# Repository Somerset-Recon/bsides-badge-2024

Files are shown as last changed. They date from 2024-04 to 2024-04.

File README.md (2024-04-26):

# BSides Badge 2024
<div align="center">
<table>
  <tr>
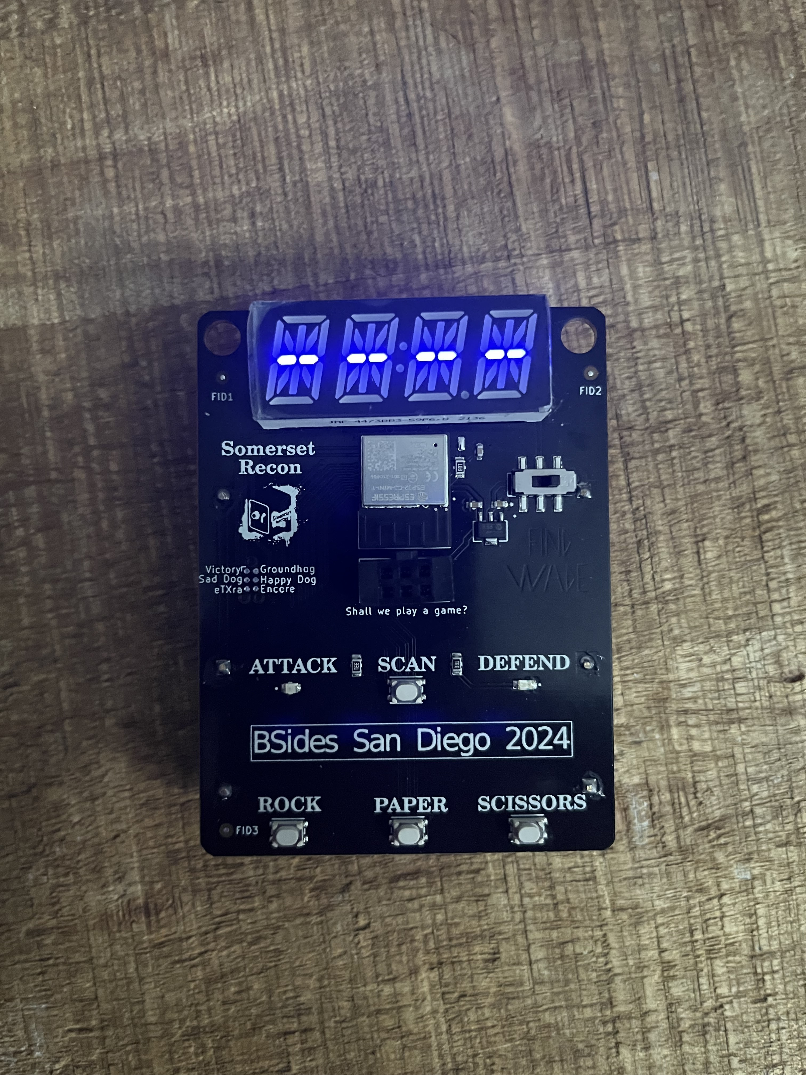
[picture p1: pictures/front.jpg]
    <td></td>
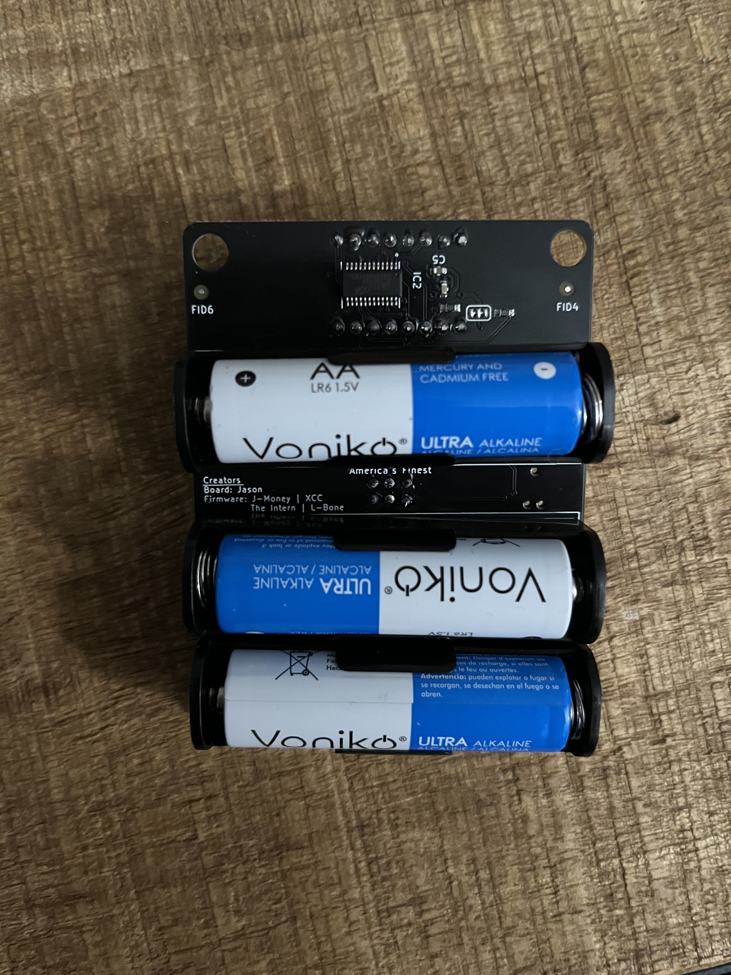
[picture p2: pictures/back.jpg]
    <td></td>
  </tr>
  <tr>
    <td><em><center>Front</center></em></td>
    <td><em><center>Back</center></em></td>
  </tr>
  <tr>
 </table>
<table>
  <tr>
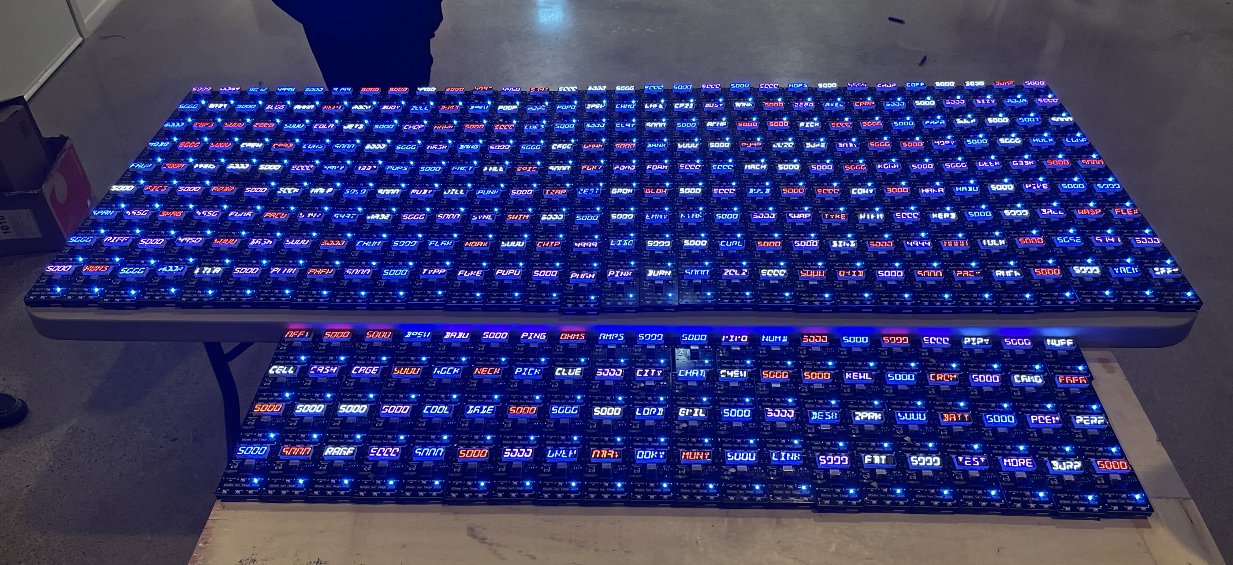
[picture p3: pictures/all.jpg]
    <td></td>
  </tr>
  <tr>
    <td align=center><em>Flashed Badges</em></td>
  </tr>
  <tr>
 </table>
 </div>

This repository contains hardware and firmware information needed to create and/or modify the Bsides Conference 2024 badge. All Gerber files, kiCad schematics, and other hardware-related files can be found in the "kiCad" folder. Associated source code and required libraries can be found in the "software" folder. We welcome BSides CTF players to submit writeups. Badge related writeups will be populated below.

Disclaimer: Somerset Recon is not liable nor responsible for any and all forks, branches, and duplication of the badge hardware or software created by an entity other than Somerset Recon.

The Badge for the San Diego Bsides Conference is a game that involves wireless rock-paper-scissors. There are hidden hacking challenges accessible over UART with a Wargames movie theme. 400 badges were distributed at the BSides San Diego 2024 Conference.

## Gameplay

The object of the game was to score the most points. Points were earned by hacking other players. The badges have two states: Attack mode and defend mode. 

 	A red LED on a badge will indicate that the player is in attack mode. Players will click the scan button. During a scan, BLE on the baddge will search for devices that are advertising (devices in defend mode). Once a connection is established, the player will be notified to choose rock, paper or scissors. The attacker gains points for each second they are connected to a defender. Once the defender notices that they are being attacked, they will choose rock, paper, or scissors. 
## WOPR Interface
<div align="center">
<table>
  <tr>
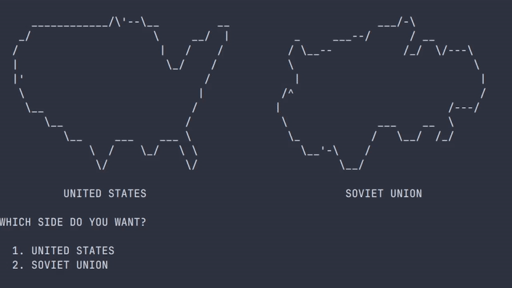
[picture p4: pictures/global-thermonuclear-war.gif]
    <td></td>
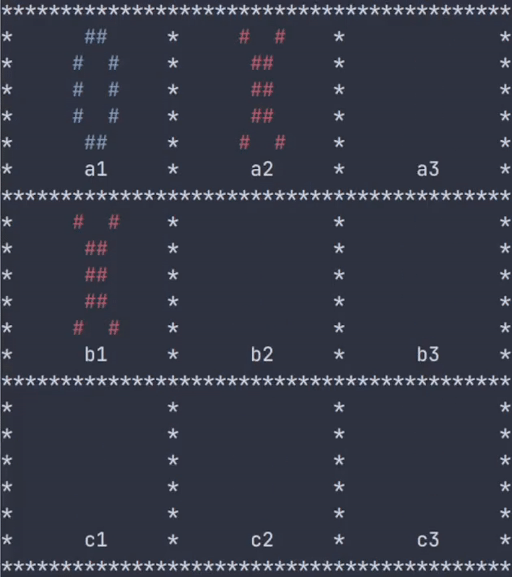
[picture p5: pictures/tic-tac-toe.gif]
    <td></td>
  </tr>
  <tr>
    <td align=center><em>Global Thermonuclear War</em></td>
    <td align=center><em>Tic-Tac-Toe</em></td>
  </tr>
  <tr>
</table>
</div>
Various challenges in the form of WOPR games are accessible using UART over the SAO connector. Each challenge contains its own flag to earn points in the BSides CTF.

# Flashing Instructions
> [!NOTE]
> In the latest source code, a cool glitch-like display will appear for the custom name when "SCAN" is held at boot. The conference badges were flashed with earlier firmware and do not have this feature. To add this glitch-like display, the badge must be flashed with the latest source code.
## Materials
- Arduino IDE
- TAG Connector (6-pin without legs)
## Procedure
1. Copy the Ticker library in this repository to the arduino library folder. Do *not* download the Ticker library via the Library Manager.
2. Open the Arduino IDE.
3. Open the source code file "latest.ino". All files in the folder should be automatically added when loaded.
4. Navigate to Board Manager and download the "esp32" board by Espressif Systems.
5. Turn on the badge and connect the TAG Connector to the TAG port. Plug the TAG connect to your computer via USB.
6. Select the board "ESP32C3 Dev Module" and choose the port that the badge is connected to.
7. Press Upload. If the compilation fails, ensure you have all necessary libraries downloaded.

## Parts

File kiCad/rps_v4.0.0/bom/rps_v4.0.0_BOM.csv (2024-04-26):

Id | Designator | Footprint | Quantity | Designation | Supplier and ref
1 | BT1,BT2,BT3 | BatteryHolder_Keystone_2460_1xAANO_HOLES | 3 | 2460
2 | R2,R1 | R-0805 | 2 | 330
3 | D2 | LED_0805_Red | 1 | RED
4 | U2 | SILSMART_DISPLAY | 1 | SILSMART_DISPLAY
5 | SW5 | ON_OFF_SW_JS202011SCQN | 1 | JS202011SCQN
6 | SW1,SW2,SW3,SW4 | PTS815_button | 4 | PTS815 SJM 250 SMTR LFS
7 | FID3,FID2,FID1,FID5,FID6,FID4 | Fiducial_0.75mm_Mask2.25mm | 6 | Fiducial
8 | C2,C3,C1 | CAP_0603_1UF | 3 | 1UF
9 | R3 | RES_0805_10K | 1 | 10K
10 | D1 | LED_0805_BLUE | 1 | BLUE
11 | J1 | SAO_CONN6_D03-ST-BK_SUL | 1 | SAO
12 | U1 | ESP32-C3-MINI-1-N4 | 1 | ESP32-C3-MINI-1-N4
13 | U3 | MCP1700_LDO | 1 | MCP1700T-3302E/MB
14 | TP1 | SolderWirePad_1x01_SMD_1x2mm | 1 | TestPoint
15 | IC1 | HT16K33A-24SOP | 1 | HT16K33
16 | R5,R4 | 0603 | 2 | 2K2
17 | C5 | CAP_0603_10UF | 1 | 10UF
18 | C4 | CAP_0603_0.1UF | 1 | 0.1UF

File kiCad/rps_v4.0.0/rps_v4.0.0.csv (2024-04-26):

Source: | /home/chargen/badge_2024/kiCad/rps_v4.0.0/rps_v4.0.0.kicad_sch
Date: | Sun 14 Jan 2024 09:23:05 AM PST
Tool: | Eeschema 7.0.10-7.0.10~ubuntu22.04.1
Generator: | /usr/share/kicad/plugins/bom_csv_grouped_by_value.py
Component Count: | 32
Collated Components:
Item | Qty | Reference(s) | Value | LibPart | Footprint | Datasheet | DNP | Availability | Check_prices | Description | MANUFACTURER | MAXIMUM_PACKAGE_HEIGHT | MF | MP | PARTREV | PROD_ID | Package | Price | Purchase-URL | STANDARD | SnapEDA_Link
1 | 3 | BT1, BT2, BT3 | 2460 | rps_v4.0.0_symbols_library:2460_AA_Battery_Holder | rps_v4.0_footprint_library:BatteryHolder_Keystone_2460_1xAANO_HOLES | https://www.keyelco.com/userAssets/file/M65p28.pdf |  |  |  | Battery Holder for the AA batteries to power the board. | Keystone Electronics | 13.89mm |  |  |  |  |  | .70 | https://www.digikey.com/en/products/detail/keystone-electronics/2460/280629 |  | https://www.digikey.com/en/models/280629
2 | 3 | C1, C2, C3 | 1UF | rps_v4.0.0_symbols_library:Capacitor-0603 | rps_v4.0_footprint_library:0603
3 | 1 | C4 | 0.1UF | rps_v4.0.0_symbols_library:Capacitor-0603 | rps_v4.0_footprint_library:0603 | https://mm.digikey.com/Volume0/opasdata/d220001/medias/docus/658/CL10B104KB8NNWC_Spec.pdf |  |  |  |  |  |  |  |  |  |  |  | .006 | https://www.digikey.com/en/products/detail/samsung-electro-mechanics/CL10B104KB8NNWC/3887593 |  | https://www.digikey.com/en/models/3887593
4 | 1 | C5 | 10UF | rps_v4.0.0_symbols_library:Capacitor-0603 | rps_v4.0_footprint_library:0603 | https://mm.digikey.com/Volume0/opasdata/d220001/medias/docus/609/CL10A106MQ8NNNC_Spec.pdf |  |  |  |  |  |  |  |  |  |  |  | .030 | https://www.digikey.com/en/products/detail/samsung-electro-mechanics/CL10A106MQ8NNNC/3886777 |  | https://www.digikey.com/en/models/3886777
5 | 1 | D3 | RED | rps_v4.0.0_symbols_library:LED-0805 | rps_v4.0_footprint_library:LED-0805 | https://dammedia.osram.info/media/resource/hires/osram-dam-5178068/LS%20R976_EN.pdf |  |  |  |  |  |  |  |  |  |  |  | .063 | https://www.digikey.com/en/products/detail/ams-osram-usa-inc/LS-R976-NR-1/1227987 |  | https://www.digikey.com/en/models/1227987
6 | 1 | D4 | BLUE | :LED-0805_1 | rps_v4.0_footprint_library:LED-0805 | https://optoelectronics.liteon.com/upload/download/DS22-2000-233/LTST-C171TBKT(0630).pdf |  |  |  |  |  |  |  |  |  |  |  | .11 | https://www.digikey.com/en/products/detail/liteon/LTST-C171TBKT/388528 |  | https://www.digikey.com/en/models/388528
7 | 6 | FID1, FID2, FID3, FID4, FID5, FID6 | Fiducial | rps_v4.0.0_symbols_library:Fiducial | rps_v4.0_footprint_library:Fiducial_0.75mm_Mask2.25mm | ~
8 | 1 | IC2 | HT16K33 | rps_v4.0.0_symbols_library:HT16K33 | rps_v4.0_footprint_library:HT16K33 | https://www.digikey.com/en/htmldatasheets/production/2070902/0/0/1/ht16k33 |  |  |  |  |  |  |  |  |  | IC-14891 |  | .61
9 | 1 | J1 | SAO | rps_v4.0.0_symbols_library:CONN_02x03_SFH11-PBPC-D03-ST-BK | rps_v4.0_footprint_library:SAO_CONN6_D03-ST-BK_SUL | https://s3.amazonaws.com/catalogspreads-pdf/PAGE123%20.100%20SFH11%20SERIES%20FEMALE%20HDR%20ST%20RA.pdf |  |  |  |  |  |  |  |  |  |  |  | .42 | https://www.digikey.com/en/products/detail/sullins-connector-solutions/SFH11-NBPC-D03-ST-BK/4558818 |  | https://www.digikey.com/en/models/4558878
10 | 3 | R1, R2, R4 | 10K | rps_v4.0.0_symbols_library:R_0805 | rps_v4.0_footprint_library:R-0805 | https://www.seielect.com/catalog/sei-rmcf_rmcp.pdf |  |  |  |  |  |  |  |  |  |  |  | .005 | https://www.digikey.com/en/products/detail/stackpole-electronics-inc/RMCF0805JT10K0/1757762 |  | https://www.digikey.com/en/models/1757762
11 | 2 | R6, R7 | 2K2 | rps_v4.0.0_symbols_library:R-0603 | rps_v4.0_footprint_library:0603 | https://www.yageo.com/upload/media/product/productsearch/datasheet/rchip/PYu-RT_1-to-0.01_RoHS_L_15.pdf |  |  |  |  |  |  |  |  |  |  |  | .046 | https://www.digikey.com/en/products/detail/yageo/RT0603BRD072K2L/1072430 |  | https://www.digikey.com/en/models/1072430
12 | 1 | SW1 | PTS815 SJM 250 SMTR LFS | :PTS815_SJM_250_SMTR_LFS_1 | rps_v4.0_footprint_library:PTS815_button | https://www.ckswitches.com/media/2728/pts815.pdf |  |  |  |  | C&K |  |  |  |  |  |  | .12 | https://www.digikey.com/en/products/detail/c-k/PTS815-SJM-250-SMTR-LFS/9947846 |  | https://www.digikey.com/en/models/9947846
13 | 1 | SW2 | PTS815 SJM 250 SMTR LFS | :PTS815_SJM_250_SMTR_LFS_2 | rps_v4.0_footprint_library:PTS815_button | https://www.ckswitches.com/media/2728/pts815.pdf |  |  |  |  | C&K |  |  |  |  |  |  | .12 | https://www.digikey.com/en/products/detail/c-k/PTS815-SJM-250-SMTR-LFS/9947846 |  | https://www.digikey.com/en/models/9947846
14 | 1 | SW3 | PTS815 SJM 250 SMTR LFS | :PTS815_SJM_250_SMTR_LFS_3 | rps_v4.0_footprint_library:PTS815_button | https://www.ckswitches.com/media/2728/pts815.pdf |  |  |  |  | C&K |  |  |  |  |  |  | .12 | https://www.digikey.com/en/products/detail/c-k/PTS815-SJM-250-SMTR-LFS/9947846 |  | https://www.digikey.com/en/models/9947846
15 | 1 | SW4 | PTS815 SJM 250 SMTR LFS | rps_v4.0.0_symbols_library:PTS815_SJM_250_SMTR_LFS | rps_v4.0_footprint_library:PTS815_button | https://www.ckswitches.com/media/2728/pts815.pdf |  |  |  |  | C&K |  |  |  |  |  |  | .12 | https://www.digikey.com/en/products/detail/c-k/PTS815-SJM-250-SMTR-LFS/9947846 |  | https://www.digikey.com/en/models/9947846
16 | 1 | SW5 | JS202011SCQN | rps_v4.0.0_symbols_library:ON_OFF_6PIN_JS202011SCQN | rps_v4.0_footprint_library:ON_OFF_SW_JS202011SCQN | https://www.ckswitches.com/media/1422/js.pdf |  |  |  |  |  |  |  |  |  |  |  | .47 | https://www.digikey.com/en/products/detail/c-k/JS202011SCQN/2094299 |  | https://www.digikey.com/en/models/2094299
17 | 1 | TP1 | TestPoint | rps_v4.0.0_symbols_library:TestPoint | rps_v4.0_footprint_library:SolderWirePad_1x01_SMD_1x2mm | ~
18 | 1 | U1 | ESP32-C3-MINI-1-N4 | rps_v4.0.0_symbols_library:ESP32-C3-MINI-1-N4 | rps_v4.0_footprint_library:ESP32-C3-MINI-1-N4 | https://www.espressif.com/sites/default/files/documentation/esp32-c3-mini-1_datasheet_en.pdf |  | In Stock | https://www.snapeda.com/parts/ESP32-C3-MINI-1-N4/Espressif+Systems/view-part/?ref=eda | Bluetooth, WiFi 802.11b/g/n, Bluetooth v5.0 Transceiver Module 2.412GHz ~ 2.484GHz PCB Trace Surface Mount | Espressif Systems | 2.55mm | Espressif Systems | ESP32-C3-MINI-1-N4 | v1.0 |  | SMD-53 Espressif Systems | 1.80 | https://www.snapeda.com/api/url_track_click_mouser/?unipart_id=5656579&manufacturer=Espressif Systems&part_name=ESP32-C3-MINI-1-N4&search_term=esp32-c3-mini | Manufacturer Recommendations | https://www.snapeda.com/parts/ESP32-C3-MINI-1-N4/Espressif+Systems/view-part/?ref=snap
19 | 1 | U2 | SILSMART_DISPLAY | rps_v4.0.0_symbols_library:SILSMART_DISPLAY | rps_v4.0_footprint_library:SILSMART_DISPLAY | https://cdn.sparkfun.com/assets/a/9/d/a/4/JMF-4473BS4-059-P6.8.pdf |  |  |  |  |  |  |  |  |  | COMP-14892 |  | 2.50 | https://www.digikey.com/en/products/detail/sparkfun-electronics/COM-21217/16892550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
20 | 1 | U3 | MCP1700T-3302E/MB | rps_v4.0.0_symbols_library:MCP1700T-3302E_MB | rps_v4.0_footprint_library:MCP1700_LDO | MCP1700T-3302E/MBhttps://ww1.microchip.com/downloads/en/DeviceDoc/MCP1700-Data-Sheet-20001826F.pdf

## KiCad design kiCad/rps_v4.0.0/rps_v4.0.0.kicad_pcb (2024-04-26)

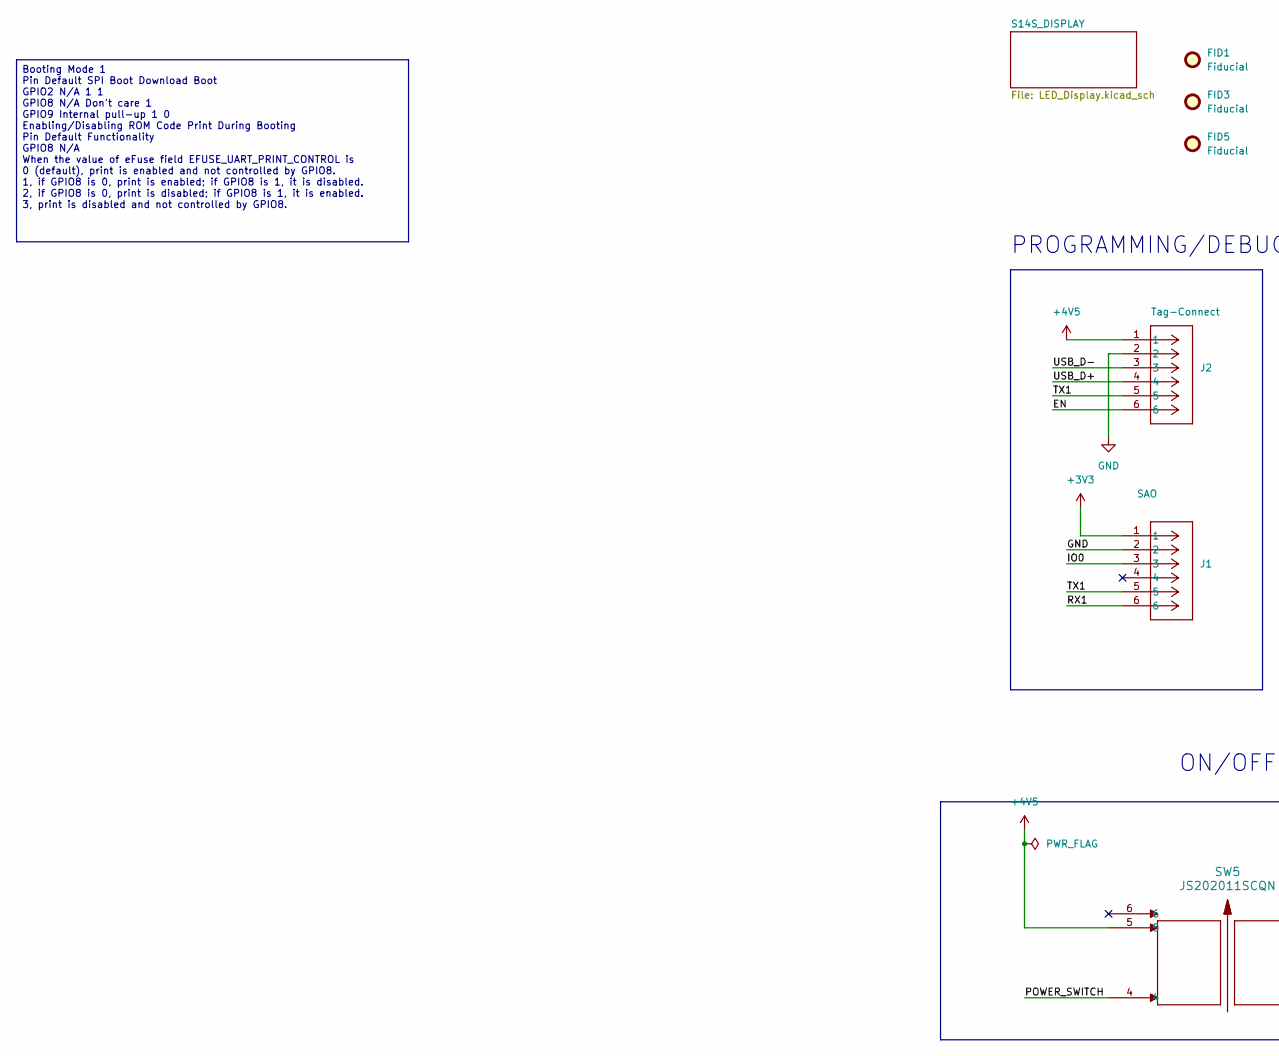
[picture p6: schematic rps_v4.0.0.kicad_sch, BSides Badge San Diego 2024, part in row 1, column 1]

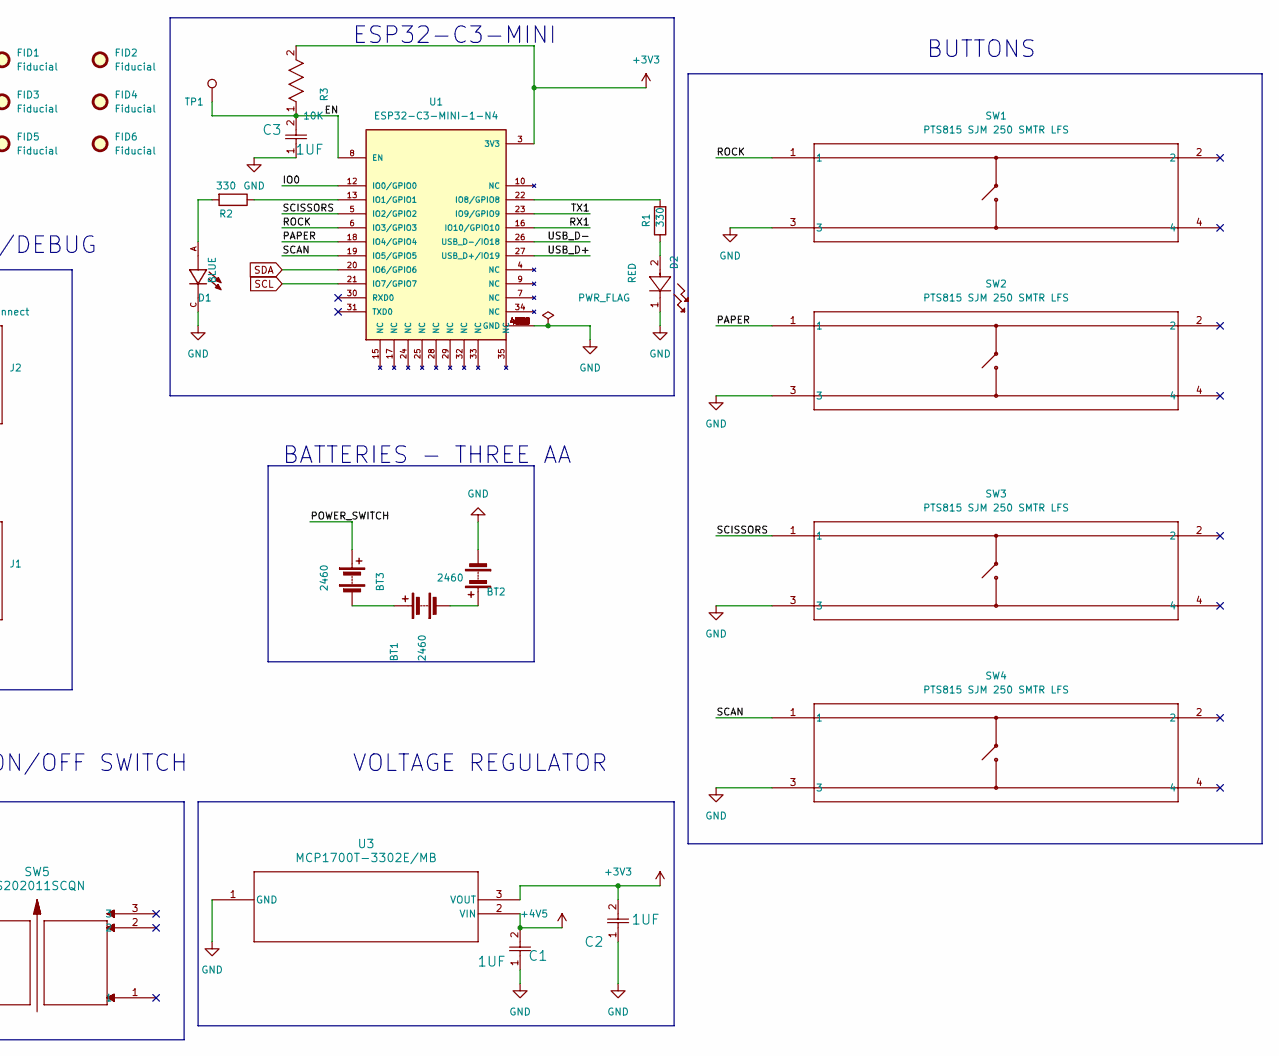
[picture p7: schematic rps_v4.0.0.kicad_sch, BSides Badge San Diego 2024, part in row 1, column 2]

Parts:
BT1, BT2, BT3: 2460; BatteryHolder_Keystone_2460_1xAANO_HOLES
C1, C2, C3: 1UF; CAP_0603_1UF
D1: BLUE; LED_0805_BLUE
D2: RED; LED_0805_Red
FID1, FID2, FID3, FID4, FID5, FID6: Fiducial; Fiducial_0.75mm_Mask2.25mm
J1: SAO; SAO_CONN6_D03-ST-BK_SUL
J2: Tag-Connect; Tag-Connect_TC2030-IDC-NL_2x03_P1.27mm_Vertical
R1, R2: 330; R-0805
R3: 10K; RES_0805_10K
SW1, SW2, SW3, SW4: PTS815 SJM 250 SMTR LFS; PTS815_button
SW5: JS202011SCQN; ON_OFF_SW_JS202011SCQN
TP1: TestPoint; SolderWirePad_1x01_SMD_1x2mm
U1: ESP32-C3-MINI-1-N4; PARTREV v1.0
U3: MCP1700T-3302E/MB; MCP1700_LDO

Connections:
+3V3: C2.2, J1.1, R3.2, U1.3 (3V3), U3.3 (VOUT)
+4V5: C1.2, J2.1, SW5.5, U3.2 (VIN); also elsewhere on the board
/EN: C3.2, J2.6, R3.1, TP1.1, U1.8 (EN)
/IO0: J1.3, U1.12 (IO0/GPIO0)
/PAPER: SW2.1, U1.18 (IO4/GPIO4)
/POWER_SWITCH: BT3.1 (+), SW5.4
/ROCK: SW1.1, U1.6 (IO3/GPIO3)
/RX1: J1.6, U1.16 (IO10/GPIO10)
/SCAN: SW4.1, U1.19 (IO5/GPIO5)
/SCISSORS: SW3.1, U1.5 (IO2/GPIO2)
/TX1: J1.5, J2.5, U1.23 (IO9/GPIO9)
/USB_D+: J2.4, U1.27 (USB_D+/IO19)
/USB_D-: J2.3, U1.26 (USB_D-/IO18)
GND: BT2.2 (-), C1.1, C2.1, C3.1, D1.C, D2.1, J1.2, J2.2, SW1.3, SW2.3, SW3.3, SW4.3, U1.1 (GND), U1.2 (GND), U1.11 (GND), U1.14 (GND), U1.36 (GND), U1.37 (GND), U1.38 (GND), U1.39 (GND), U1.40 (GND), U1.41 (GND), U1.42 (GND), U1.43 (GND), U1.44 (GND), U1.45 (GND), U1.46 (GND), U1.47 (GND), U1.48 (GND), U1.49_1 (GND), U1.49_2 (GND), U1.49_3 (GND), U1.49_4 (GND), U1.49_5 (GND), U1.49_6 (GND), U1.49_7 (GND), U1.49_8 (GND), U1.49_9 (GND), U1.50 (GND), U1.51 (GND), U1.52 (GND), U1.53 (GND), U3.1 (GND); also elsewhere on the board
unnamed: BT1.1 (+), BT3.2 (-)
unnamed: BT1.2 (-), BT2.1 (+)
unnamed: D1.A, R2.2
unnamed: D2.2, R1.1
unnamed: R2.1, U1.13 (IO1/GPIO1)
unnamed: R1.2, U1.22 (IO8/GPIO8)
SCL: U1.21 (IO7/GPIO7); also elsewhere on the board
SDA: U1.20 (IO6/GPIO6); also elsewhere on the board

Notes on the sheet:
ESP32-C3-MINI
ON/OFF SWITCH
VOLTAGE REGULATOR
BUTTONS
BATTERIES - THREE AA
PROGRAMMING/DEBUG
Booting Mode 1 Pin Default SPI Boot Download Boot GPIO2 N/A 1 1 GPIO8 N/A Don't care 1 GPIO9 Internal pull-up 1 0 Enabling/Disabling ROM Code Print During Booting Pin Default Functionality GPIO8 N/A When the value of eFuse field EFUSE_UART_PRINT_CONTROL is 0 (default), print is enabled and not cont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

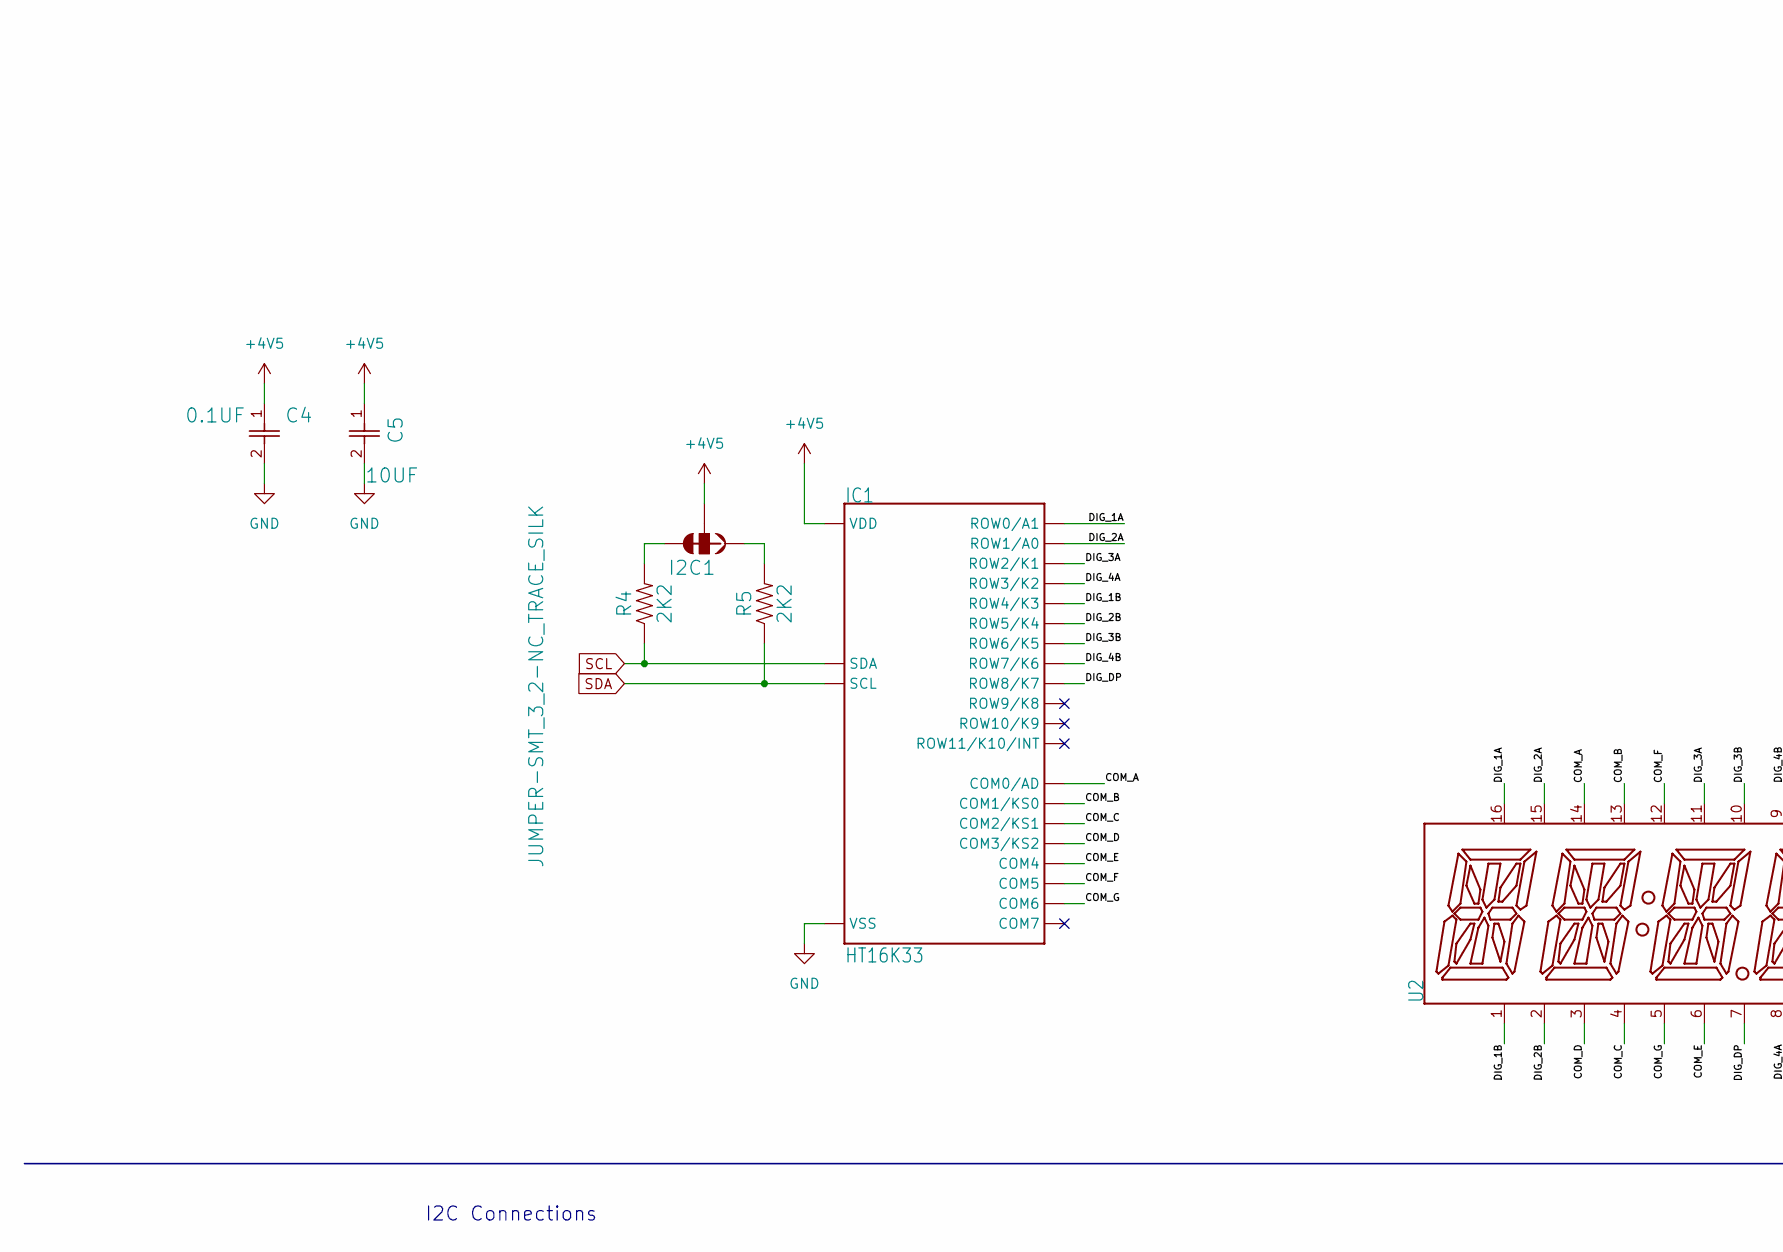
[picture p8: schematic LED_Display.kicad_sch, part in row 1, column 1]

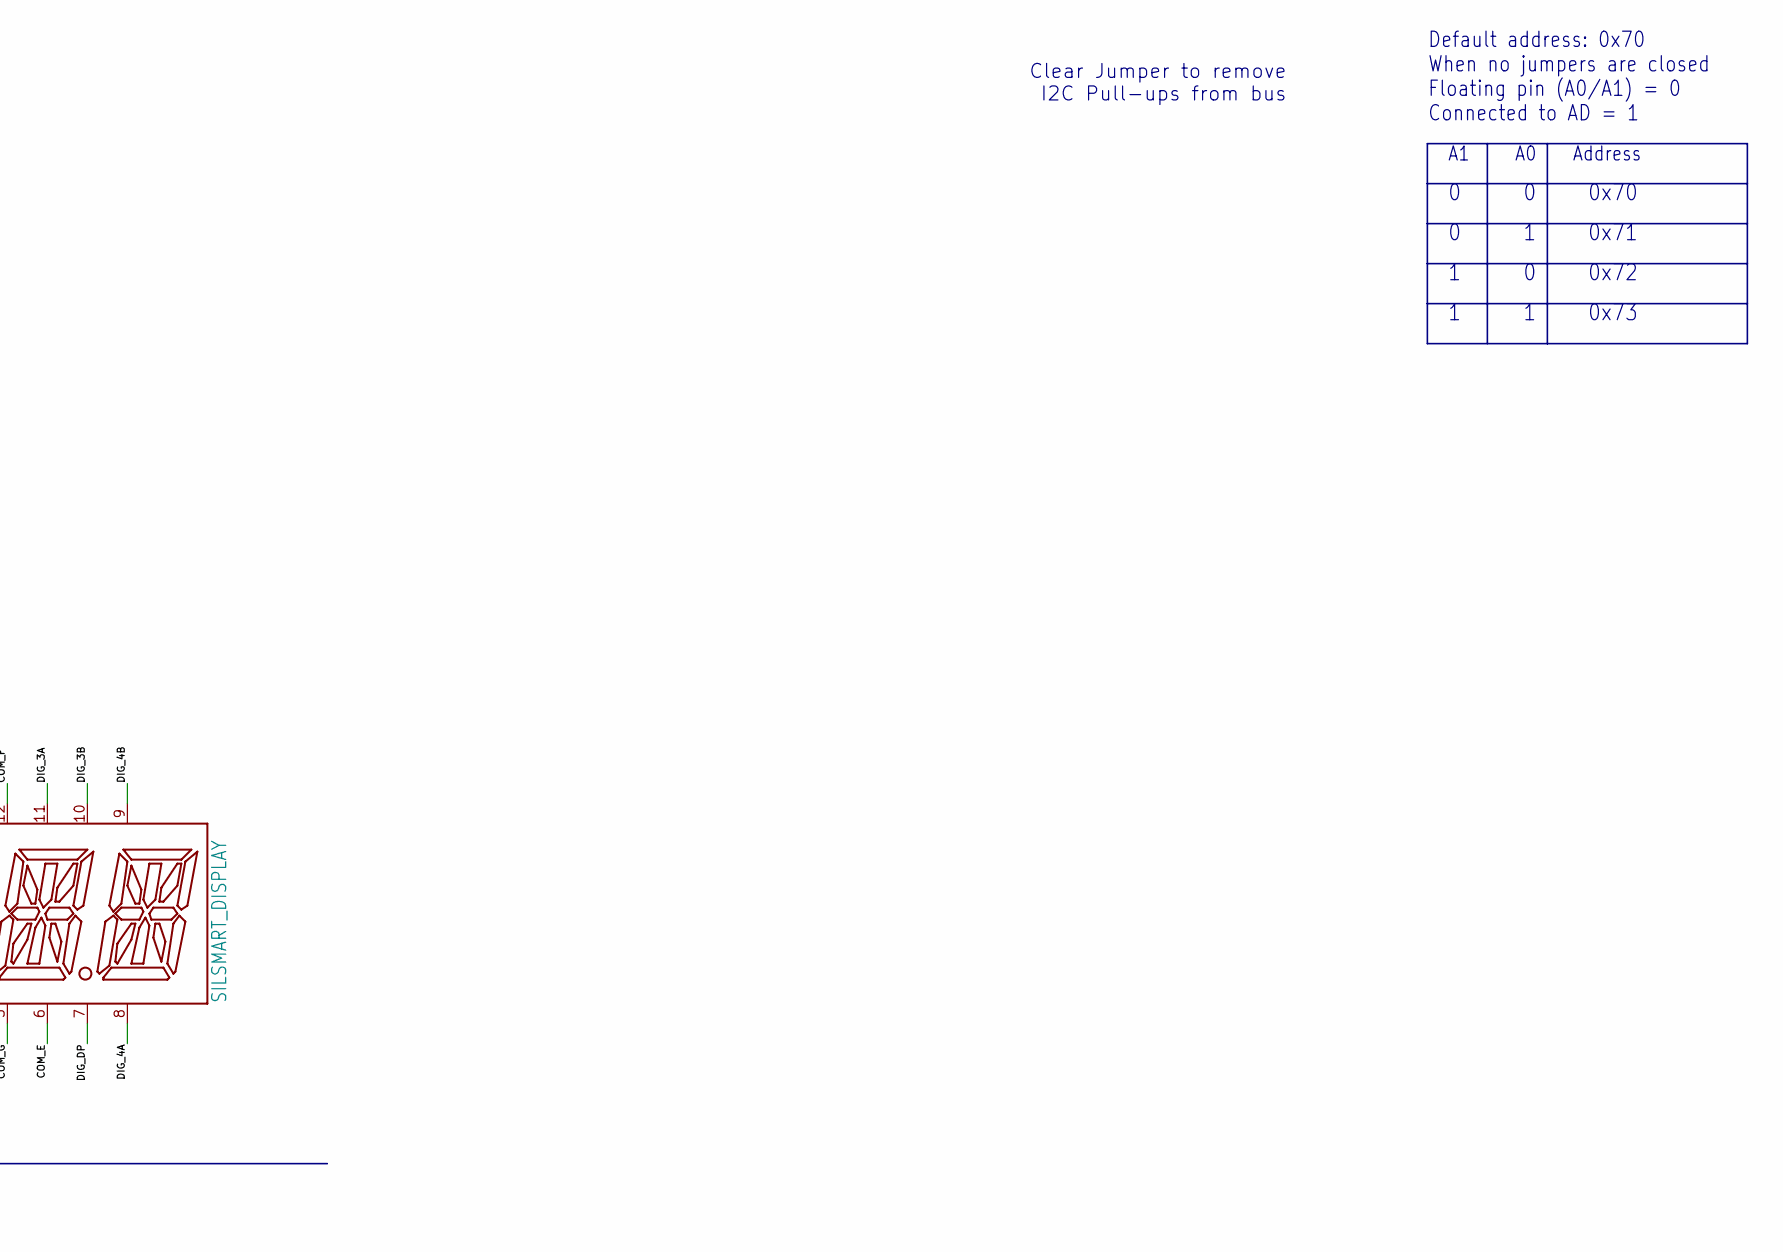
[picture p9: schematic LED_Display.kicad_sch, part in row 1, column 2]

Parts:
C4: 0.1UF; CAP_0603_0.1UF
C5: 10UF; CAP_0603_10UF
I2C1: JUMPER-SMT_3_2-NC_TRACE_SILK; SMT-JUMPER_3_2-NC_TRACE_SILK
IC1: HT16K33; HT16K33A-24SOP
R4, R5: 2K2; 0603
U2: SILSMART_DISPLAY

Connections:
+4V5: C4.1, C5.1, I2C1.2, IC1.24 (VDD); also elsewhere on the board
/S14S_DISPLAY/COM_A: IC1.2 (COM0/AD), U2.14 (COM_A)
/S14S_DISPLAY/COM_B: IC1.3 (COM1/KS0), U2.13 (COM_B)
/S14S_DISPLAY/COM_C: IC1.4 (COM2/KS1), U2.4 (COM_C)
/S14S_DISPLAY/COM_D: IC1.5 (COM3/KS2), U2.3 (COM_D)
/S14S_DISPLAY/COM_E: IC1.6 (COM4), U2.6 (COM_E)
/S14S_DISPLAY/COM_F: IC1.7 (COM5), U2.12 (COM_F)
/S14S_DISPLAY/COM_G: IC1.8 (COM6), U2.5 (COM_G1)
/S14S_DISPLAY/DIG_1A: IC1.21 (ROW0/A1), U2.16 (DIG_1A)
/S14S_DISPLAY/DIG_1B: IC1.17 (ROW4/K3), U2.1 (DIG_1B)
/S14S_DISPLAY/DIG_2A: IC1.20 (ROW1/A0), U2.15 (DIG_2A)
/S14S_DISPLAY/DIG_2B: IC1.16 (ROW5/K4), U2.2 (DIG_2B)
/S14S_DISPLAY/DIG_3A: IC1.19 (ROW2/K1), U2.11 (DIG_3A)
/S14S_DISPLAY/DIG_3B: IC1.15 (ROW6/K5), U2.10 (DIG_3B)
/S14S_DISPLAY/DIG_4A: IC1.18 (ROW3/K2), U2.8 (DIG_4A)
/S14S_DISPLAY/DIG_4B: IC1.14 (ROW7/K6), U2.9 (DIG_4B)
/S14S_DISPLAY/DIG_DP: IC1.13 (ROW8/K7), U2.7 (DIG_DP)
GND: C4.2, C5.2, IC1.1 (VSS); also elsewhere on the board
unnamed: I2C1.1, R5.2
unnamed: I2C1.3, R4.2
SCL: IC1.23 (SDA), R4.1; also elsewhere on the board
SDA: IC1.22 (SCL), R5.1; also elsewhere on the board

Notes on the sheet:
Default address: 0x70 When no jumpers are closed Floating pin (A0/A1) = 0 Connected to AD = 1
Clear Jumper to remove I2C Pull-ups from bus
1 1 0x73
0 1 0x71
0 0 0x70
1 0 0x72
I2C Connections
A1 A0 Address

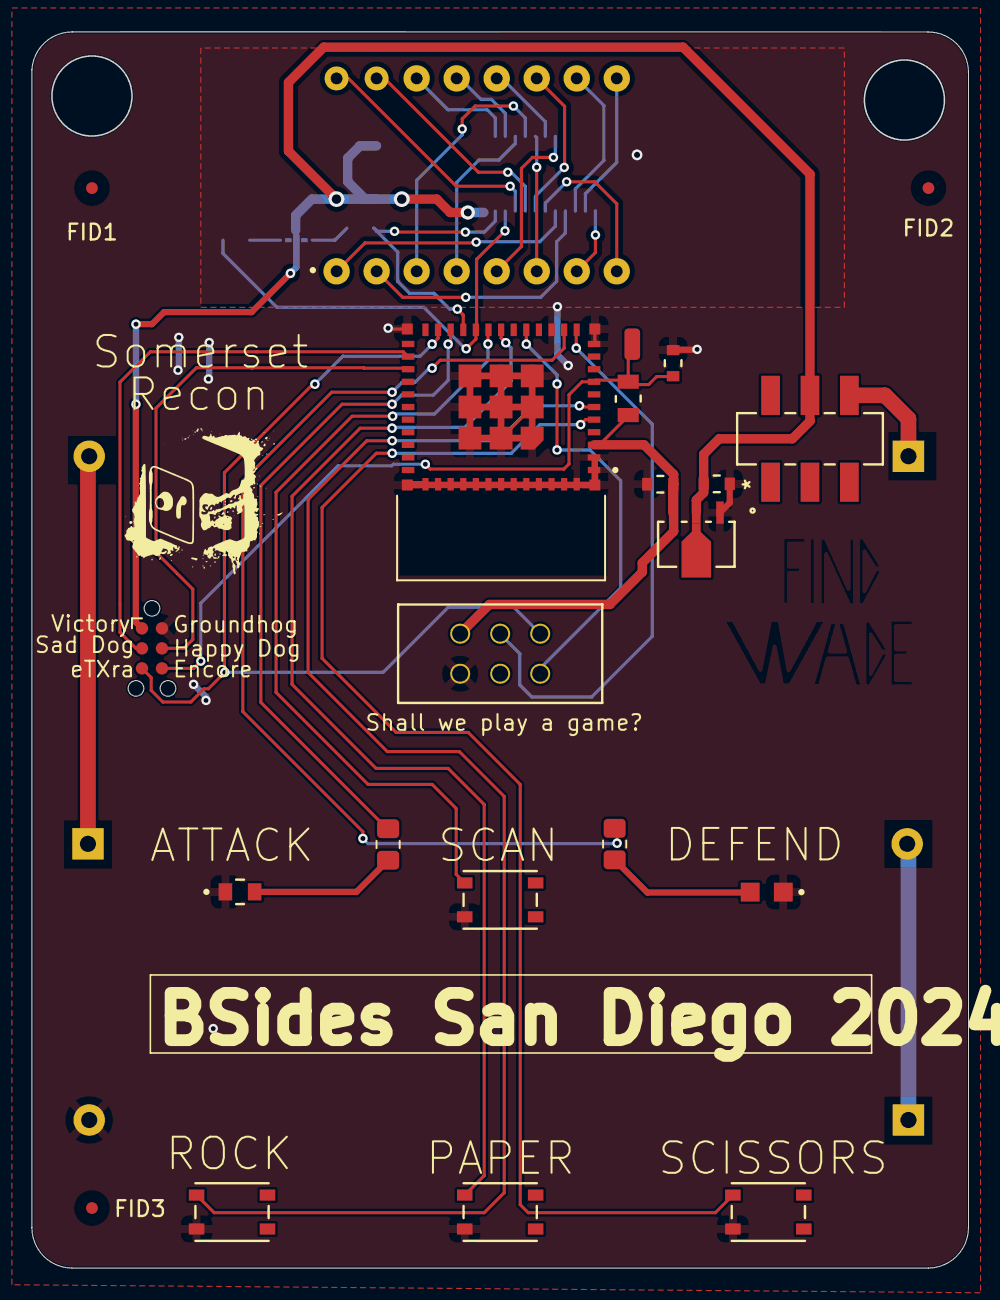
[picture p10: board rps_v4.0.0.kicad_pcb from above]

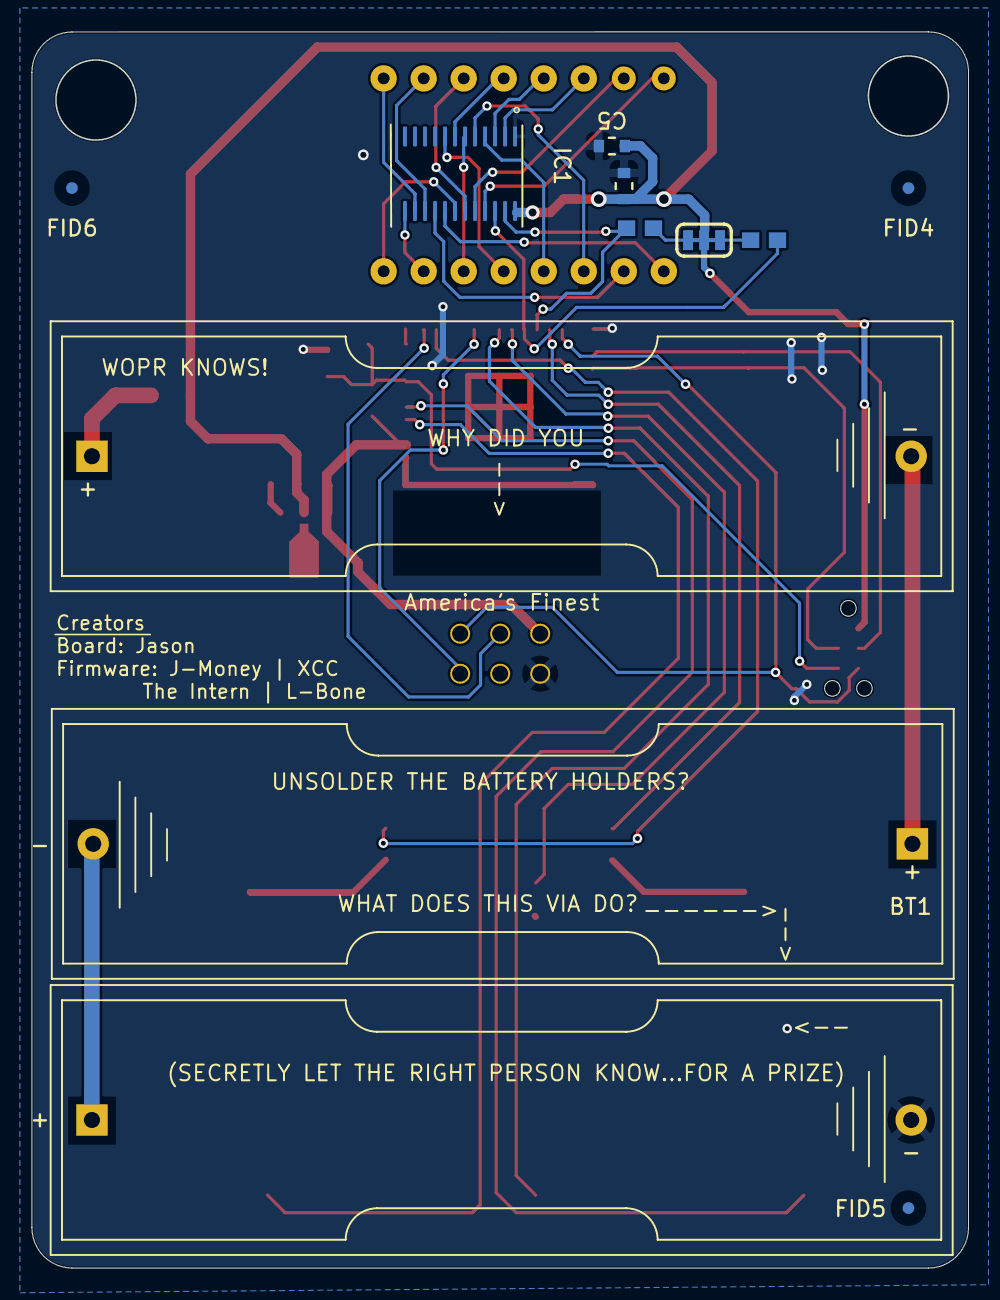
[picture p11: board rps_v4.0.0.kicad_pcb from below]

Board: 2 copper layers, 59.4 x 78.4 mm, 34 parts (12 on the bottom side), 40 nets.

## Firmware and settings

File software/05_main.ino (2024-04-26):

void setup() {
  Serial.begin(115200);
  Wire.begin(7, 6);  //Join I2C bus

  if (display.begin() == false) {
    Serial.println("Device did not acknowledge! Freezing.");
    while (1)
      ;
  }
  Serial.println("Display acknowledged.");

  if (!SPIFFS.begin(true)) {
    Serial.println("SPIFFS Mount Failed");
    return;
  }

  display.setBrightness(4);

  bool isFirstBoot = checkFirstBoot();
  // If it's the first boot, perform initialization
  if (isFirstBoot) {
    Serial.println("First Boot");
    // Set the initial value to 5000
    health = 5000;
    // Save the initial value to file
    saveHealth();
  } else {
    // Restore integer value from file
    restoreHealth();
  }


  pinMode(ATTACK_LED, OUTPUT);
  pinMode(DEFEND_LED, OUTPUT);

  pinMode(SCISSOR, INPUT_PULLUP);
  pinMode(ROCK, INPUT_PULLUP);
  pinMode(PAPER, INPUT_PULLUP);
  pinMode(SCAN, INPUT_PULLUP);

  if (digitalRead(ROCK) == 0 && digitalRead(PAPER) == 0 && digitalRead(SCISSORS) == 0) {
    health += 300;
    saveHealth();
  } else if (digitalRead(SCAN) == 0 && digitalRead(ROCK) == 1 && digitalRead(PAPER) == 1 && digitalRead(SCISSORS) == 1){
    nameGlitch = true; //if hold scan during boot, glitch display name while flashing
  }
  // Save the flag indicating it's not the first boot
  saveBootFlag();

  Serial.println("Starting BLE work!");
  BLEDevice::init(DEV_NAME);
  BLEDevice::setPower(ESP_PWR_LVL_N3, ESP_BLE_PWR_TYPE_DEFAULT);
  BLEDevice::setPower(ESP_PWR_LVL_N3, ESP_BLE_PWR_TYPE_ADV);
  BLEDevice::setPower(ESP_PWR_LVL_N3, ESP_BLE_PWR_TYPE_SCAN);
  BLEServer* pServer = BLEDevice::createServer();

  // Set the callback functions for connect and disconnect events
  pServer->setCallbacks(new MyServerCallbacks());

  BLEService* pService = pServer->createService(SERVICE_UUID);
  BLECharacteristic* pCharacteristic = pService->createCharacteristic(
    CHARACTERISTIC_UUID,
    BLECharacteristic::PROPERTY_READ | BLECharacteristic::PROPERTY_WRITE);

  // Set the callback function for write events
  pCharacteristic->setCallbacks(new MyCallbacks());

  pCharacteristic->setValue("BSIDES 2024");
  pService->start();

  BLEAdvertising* pAdvertising = BLEDevice::getAdvertising();
  pAdvertising->addServiceUUID(SERVICE_UUID);
  pAdvertising->setScanResponse(true);
  pAdvertising->setMinPreferred(0x06);
  pAdvertising->setMinPreferred(0x12);
  BLEDevice::startAdvertising();

  timer1.start();
  timer2.start();

  Serial.println("Exiting setup...");
  SerialSAO.println(flag); //prints secret flag before serial initialization. Requires dumping firmware to read.

  if (boot()) { // check for cheat code
    SerialSAO.setRxBufferSize(1024);
    SerialSAO.begin(115200, SERIAL_8N1, 10, 9);
    secret_mode();
  }
}

void secret_mode() { //WOPR
  exitState = false;
  authenticated = false;
  display.clear();
  display.print("GAME");
  display.updateDisplay();
  while (!SerialSAO) {}  //game stuff here
  clear();
  println("                                                                               ");
  uint8_t flag[32] = { 0x0a, 0xe4, 0xb8, 0x1d, 0xca, 0xe8, 0x37, 0x6b, 0x54, 0x56, 0x7c, 0x5f, 0xe2, 0x44, 0xce, 0x2a, 0x39, 0x9c, 0xa1, 0xd1, 0xb8, 0x25, 0x4d, 0x5e, 0xcf, 0x07, 0xce, 0x11, 0x79, 0xc0, 0xb3, 0xb6 };
  println(flagDecrypt(flag));
  println();
  while (!insecure_login()) {}  //loops login until passes
  authenticated = true;
  println("ACCESS GRANTED");
  modem_glitch();
  delay(1000);
  clear();
  delay(1000);
  println("GREETINGS PROFESSOR FALKEN.");
  println();
  println("SHALL WE PLAY A GAME?");
  println();
  while (!exitState) {
    receive();
    println();
    receive_handle();
    empty_rx();
  }
}

void loop() {
  timer1.update();
  timer2.update();

  digitalWrite(ATTACK_LED, LOW);  // HIGH is LED On
  digitalWrite(DEFEND_LED, HIGH);

  int scanButton = digitalRead(SCAN);
  if (scanButton == LOW && !clientConnected) {
    BLEDevice::stopAdvertising();  // didnt seem to solve bug 3...maybe beecause I did startAdvertising instead of stop..... need to try with stopAdvertising -- 7PM 3/25
    handle_scan();
  }
}

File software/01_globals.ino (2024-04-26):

#define SCAN 5
#define PAPER 4
#define ROCK 3
#define SCISSORS 2
#define UP SCAN
#define DOWN PAPER
#define LEFT ROCK
#define RIGHT SCISSORS
#define INT32_MAX 2147483647

#include <HardwareSerial.h>
HardwareSerial SerialSAO(1);

#include <WString.h>

bool exitState = false;
bool authenticated = false;


const byte numChars = 32;
char receivedChars[numChars];
bool newData = false;

const String flag = "FLAG{D3C0MP1L3_W1Z@RD}"; //requires dumping firmware to read
